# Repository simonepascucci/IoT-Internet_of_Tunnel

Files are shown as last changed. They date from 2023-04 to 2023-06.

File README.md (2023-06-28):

# IOT: Internet Of Tunnel

## People

| **Name and Surname** | **LinkedIn** | **GitHub** |
| :---: | :---: | :---: |
|  `Simone Pascucci` | name (https://www.linkedin.com/in/simone-pascucci-17751126b/) | name (https://github.com/simonepascucci) |
|  `Gavriel di Nepi` |  name (https://it.linkedin.com/in/gavriel-di-nepi-544a971b1)  | name (https://github.com/gaggo00) |
| `Davide Avesani` | name (https://www.linkedin.com/in/davide-avesani-394835223/)  | name (https://github.com/aveklan) |

## Brief description

Internet Of Tunnel project is a Monitoring and Control System solution designed to monitor and manage the air quality and lighting conditions inside a car tunnel.  
With this project, we aim to improve the air quality and light levels inside car galleries, in order to improve safety and health for tunnel users, both pedestrians and vehicles, while prioritizing energy efficiency.  
As part of our objectives, we are committed to reducing the overall system energy consumption, thereby promoting sustainability and minimizing environmental impact.

## First Delivery

### Documents

- [Concept](/docs/first_delivery/Concept.md)

- [Design](/docs/first_delivery/Design.md)

- [Evaluation](/docs/first_delivery/Evaluation.md)

### Video

- [Project Presentation](https://www.youtube.com/watch?v=qPwCQMbU30s)

## Second Delivery

- [2nd delivery](/docs/second_delivery/2nd%20delivery.md)
- [Concept](/docs/second_delivery/Concept.md)
- [Design](/docs/second_delivery/Design.md)
- [Evaluation](/docs/second_delivery/Evaluation.md)

## Third Delivery

- [Concept](/docs/third_delivery/Concept.md)
- [Design](/docs/third_delivery/Design.md)
- [Evaluation](/docs/third_delivery/Evaluation.md)

### Blog Post

- [Blog Post](https://www.hackster.io/internet-of-tunnel-sapienza-project-2023/iot-internet-of-tunnel-d4070c)

### Video

- [Video Presentation](https://youtu.be/nOzBFuhrOmo)
- [Video Demonstration](https://youtu.be/TSAeotWgk8Y)
  
### Presentation

- [Project Presentation](https://www.canva.com/design/DAFnCxpepLs/c_lBvF6-MGUBneV12p3HoQ/edit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)

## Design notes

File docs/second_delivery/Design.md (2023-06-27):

# Design

This file is an updated version of [this file](/docs/second_delivery/Design.md)

The proper functioning of the system depends on several complex technical aspects to be considered. In this section, we would like to address these issues in a real case scenario, describing the solutions and adaptations made to create the prototype.

## Technical aspects

The first step before starting the development and deployment of the system is a deep analysis of the specific characteristic of the tunnel and the regulations to be complied with.  
Considering that our project aims to automatically monitor and maintain the air quality and lighting conditions prioritizing energy efficiency, the main factors to be considered are:

1. It is essential to have a regulamentation that defines the rules to be respected, to properly design the system for the specific needing. The air quality system must be based on a list of air pollutants to be monitored and their respective threshold values. Also, the minimum level of light to be guaranteed inside the tunnel must be clearly defined.  
    To make consistent assumptions for the development of this project we referred to the current Ambient Air Quality and Clean Air for Europe Standards of 2008.  
    It exposes a list of a set of air elements harmful to humans, accompanied by their respective threshold levels and permissible maximum exposure durations.  
    The following list illustrates the components on the list generated by motor vehicles:
   | Pollutant | Formula | Maximum concentration | Maximum exposition time |
   | :----------------- | :-----: | --------------------: | ----------------------- |
   | carbon dioxide | CO2 | 1800 mg/m3 | 8 hour |
   | carbon monoxide | CO | 1000 mg/m3 | 15 minutes |
   | Nitrogen dioxide | NO2 | 200 mg/m3 | 1 hour |
   | Sulphur dioxide | SO2 | 350 mg/m3 | 1 hour |
   | Particulate matter | PM10 | 50 mg/m3 | 24 hour |

2. Once the regulamentation is clarified, it is necessary to understand the characteristics of the specific tunnel in terms of dimensions, expected traffic, type of users, normal light conditions etc.  
   This characteristic facilitates the comprehension of actuator specifications, determining the required quantity and strategic placements for optimal positioning.  
   Considering the environmental conditions is also crucial to enable connectivity of the monitoring system to the internet.

## Adapting the Prototype

We tried to design a prototype that reflects in a reasonable way a real case scenario, by making feasible estimations and assumptions in relation to the equipment at our disposal.
The dimensions of the cardboard used to simulate the tunnel are 50cm x 40cm x 80cm, resulting in a total air volume of 0.18m³.

### Sensors

**Air quality**  
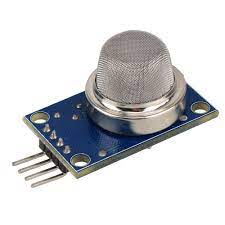
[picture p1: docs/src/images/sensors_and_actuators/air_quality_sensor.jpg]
  
The air quality sensor used is MQ-135 GAS SENSOR, suitable for detecting CO and CO2.  
This sensor vary the value of the R0 resistance depending on the concentrations of the various gases.  
The standard sensitivity characteristics of the MQ-135 sensor to different gases are illustrated below:
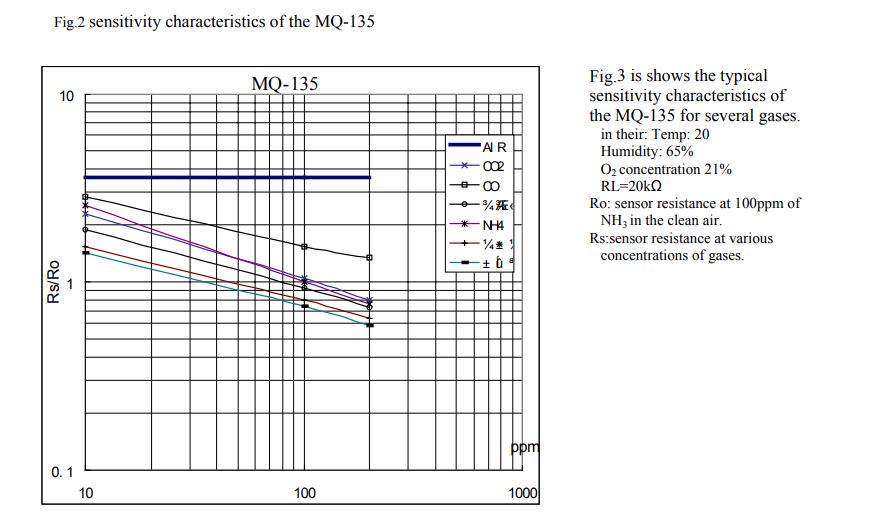
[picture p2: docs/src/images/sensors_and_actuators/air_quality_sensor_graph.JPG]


**Light**  
The light sensor used is BH1750FVI, a digital Ambient Light Sensor IC for I2C bus interface.

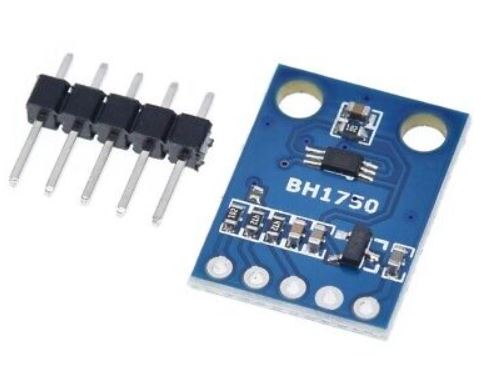
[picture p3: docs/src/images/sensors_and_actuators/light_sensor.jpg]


### Actuators

**Fan**  
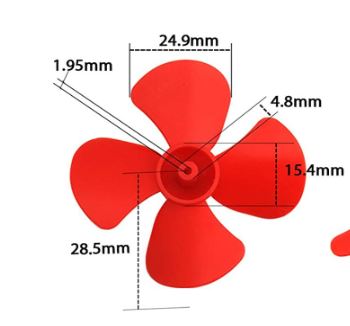
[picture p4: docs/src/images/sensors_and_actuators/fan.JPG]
  
We employed a simplistic method to estimate the fan airflow, considering that in the simulation scenario, this calculation serves as a rough approximation for guidance purposes, without requiring excessive complexity.  
The fan speed is controlled through PWM modulation, using three different speed settings.  
The formula results in:

**Airflow = fan · area · fan_speed · efficiency_factor**
| Data | value | units of measure |
| :--- | :-----: | --- |
| fan_max_speed | 44 | m/s |
| fan_mid_speed | 30 | m/s |
| fan_low_speed | 15 | m/s |
| effinciency_factor | 0.3|

| Airflow max speed | Airflow mid speed | Airflow low speed |
| :--- | :---: | --- |
| 0.033 m³/s | 0.023 m³/s | 0.011 m³/s |

With an energy consumprion of
| Airflow max speed | Airflow mid speed | Airflow low speed |
| :--- | :---: | --- |
| 100 mA | 90mA | 80mA |

Based on this estimation, we can determine the time it takes for a fan to circulate an air volume equivalent to that of the cardboard:

| Fan max speed | Fan mid speed | Fan low speed |
| :--- | :---: | --- |
| 6s | 8s | 17s |

**Light**

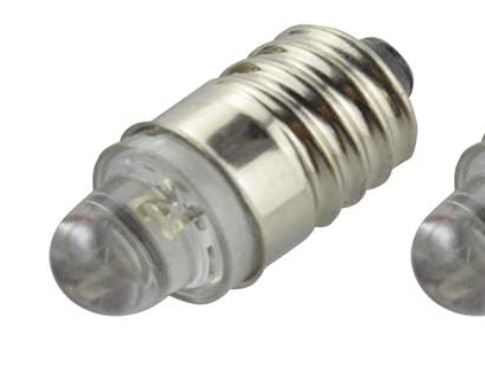
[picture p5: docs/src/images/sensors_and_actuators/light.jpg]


By positioning the light source on top of the cardboard, it generates a cone of light on the bottom with a radius of 15cm. Consequently, we opted to utilize six light bulbs to adequately illuminate the entire length of the cardboard. During measurements taken at the centre of the cone, the recorded light intensity reached approximately 1600 units.

## Managing the components

Based on the European standard mentioned earlier, the gases considered harmful to human health require a minimum exposure time of 15 minutes to pose a risk.  
We define 4 threshold of gas concentration as follows:

- **No risk treshold**: the gas concentrations are below the potentially harmful values for humans. Fan sistem is switched off.
- **Min risk treshold**: the gas concentrations are slightly above the potentially harmful values for humans. Fan sistem is switched on at 1/3 of maximum speed.
- **Mid risk treshold**: the gas concentrations are moderately above the potentially harmful values for humans. Fan sistem is switched on at 2/3 of maximum speed.
- **High risk treshold**: the gas concentrations are moderately above the potentially harmful values for humans. Fan sistem is switched on at maximum speed.

Under the condition of no risk treshold, it is reasonable to assume that monitoring air quality every 10 minutes provides a timely response from the air conditioning system.  
In the other conditions the graph below describes the different sampling period values.

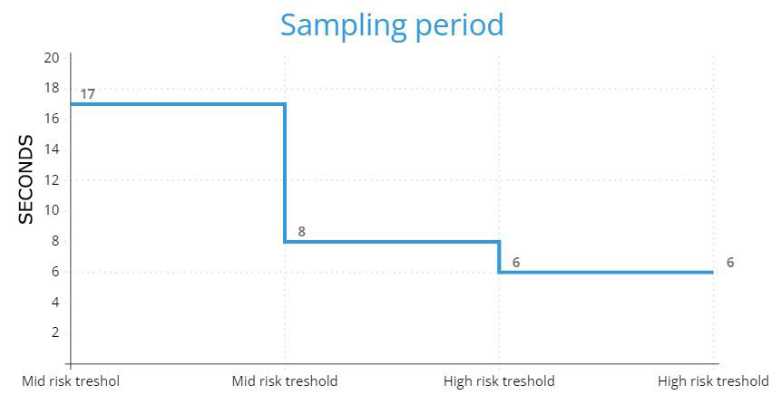
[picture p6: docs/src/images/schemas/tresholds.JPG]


The sampling period is based on the time needs for a fan to move a total volume of air equal to the volume of air of the tunnel.

## Circuit Diagrams

We utilized two separate breadboards, one for the lightning system and one for the other components as one power supply was not generating enough current.  
Additionally, it can be noticed that the DC motors are connected to a transistor rather than directly to the ESP32 PWM pin. This arrangement was necessary because the board alone can not generate enough current to power both motors. Using the transistor, the motors are supplied by the breadboard power supply, while the ESP32 exclusively controls their speed via PWM.

### Sensors & Air Conditioning System Diagram

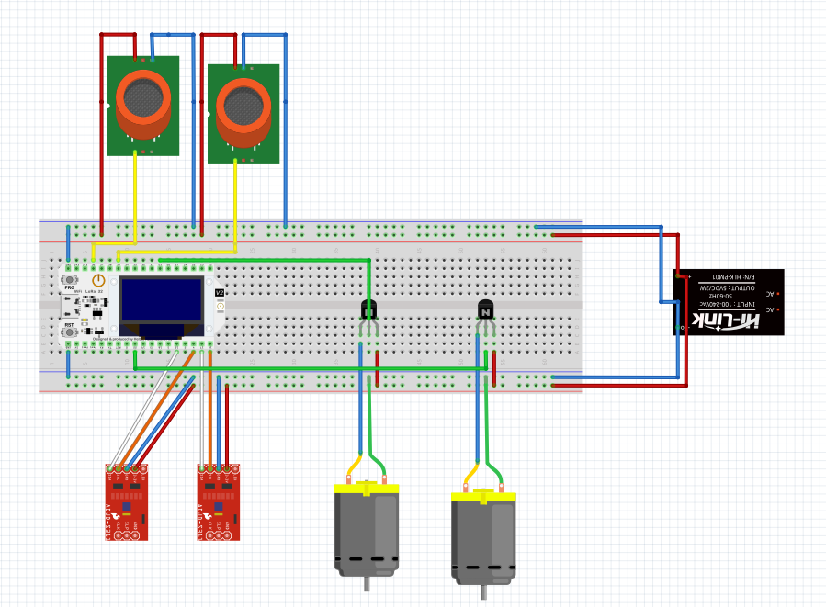
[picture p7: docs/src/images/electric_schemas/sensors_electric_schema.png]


### Lightning System Diagram

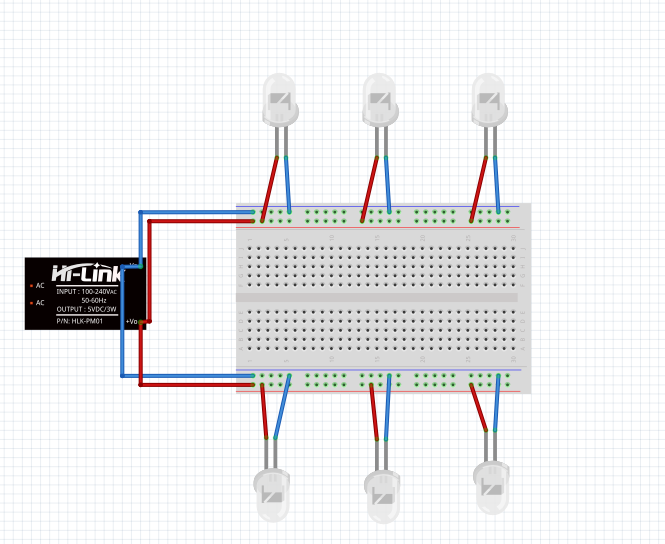
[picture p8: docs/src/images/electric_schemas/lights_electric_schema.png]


## Network architecture

The network architecture diagram and a brief description are as follows:

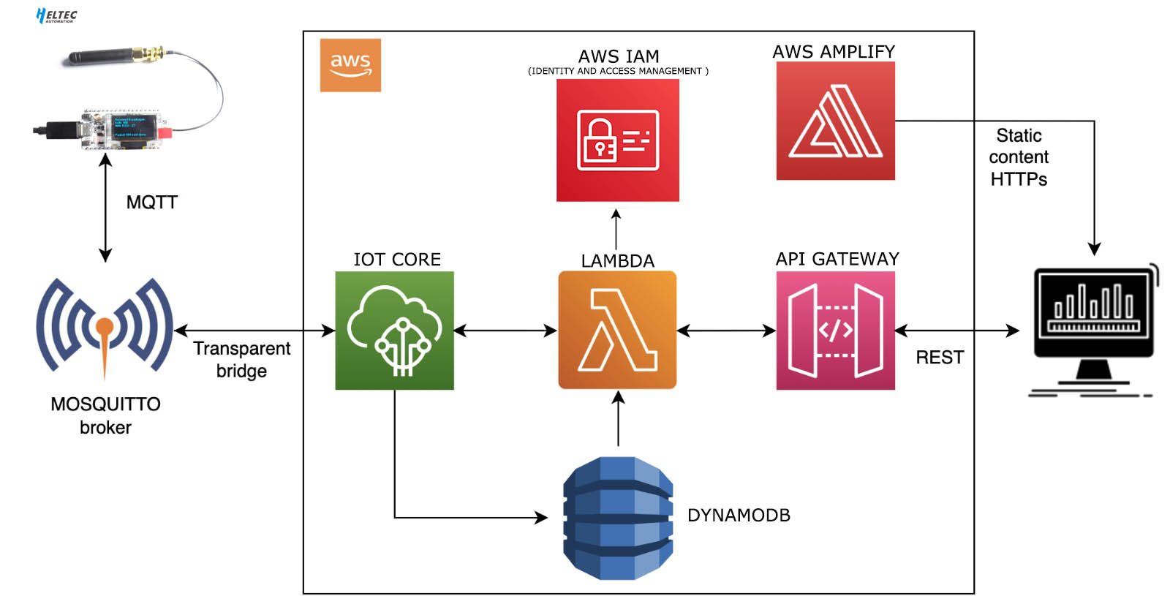
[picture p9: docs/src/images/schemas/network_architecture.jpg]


Step 1:  
ESP32 board sends data to Mosquitto MQTT broker, using the MQTT protocol. The connection is established over WiFi IPV4, with both devices connected to the same network.

Step 2:  
The broker communicates with AWS IoT Core through a Python bridge always trough the MQTT protocol. The MQTT broker and bridge utilize the same topic (tunnel), while the bridge publishes the data to AWS IoT Core on the DATA topic.

Step 3:  
Data is received on AWS IoT Core, designed as if it is an ESP32 board. This element allows to define rules to determine what actions to perform with the received data. In this way, all the data received on that specific topic is inserted into a table in DynamoDB.

Step 4:  
By utilizing a Lambda function (AWS Python function), data is retrieved from the DynamoDB. The authorization to access the database is managed by AWS IAM. The API Gateway enables the creation of a RESTful GET API connected to the Lambda function from the previous step, providing an endpoint that can be called from the web app.  
Amplify is the AWS hosting service used for deployment.

Below is a sample figure of the web app.

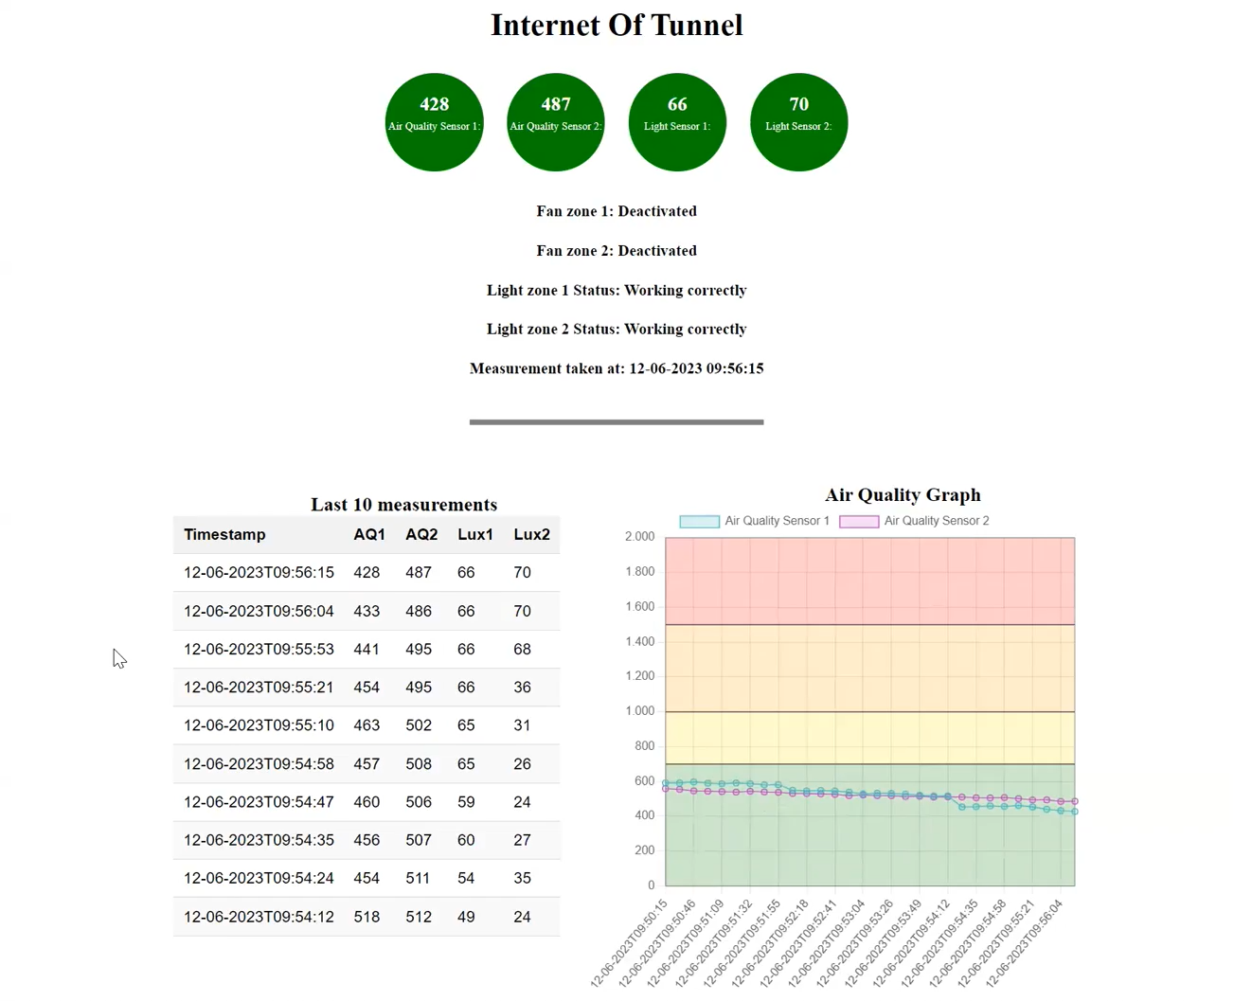
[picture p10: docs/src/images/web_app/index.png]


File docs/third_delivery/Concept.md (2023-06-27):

# Concept

This file is an updated version of [this file](/docs/second_delivery/Concept.md)

## Brief Description

Our project aims to employ a network of sensors and actuators to automate the management and monitoring of air quality and lighting conditions inside car galleries. We aim to offer a remote tool that enables remote monitoring providing a convenient means for continuous surveillance.  
The goal of this section is to provide users with a comprehensive overview of the smart tunnel, describing the system usage from their point of view.

## Tunnel operator point of view

### Deployment

To work properly, a set of sensors and actuators needs to be deployed inside the tunnel. To enable monitoring and management, it is essential that these units establish a direct connection to the board.  
The following schema provides a high level overview on how the components must be connected together.

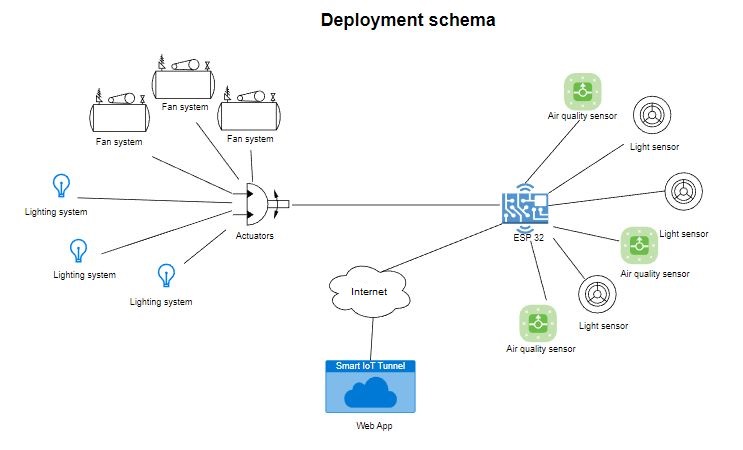
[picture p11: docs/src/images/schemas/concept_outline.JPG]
Project architecture outline


The following image shows a schematic representation of a tunnel, illustrating the positioning of sensors and actuators in a real use case.

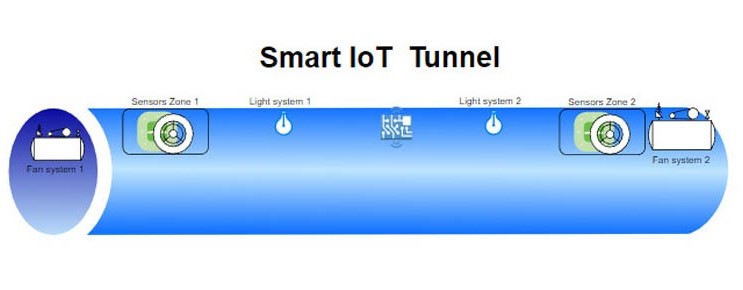
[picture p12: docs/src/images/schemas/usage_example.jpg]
Usage example


### Usage

To use the system, an operator simply needs to install the IoT sensors and actuators in the car gallery and connect them to the system's hub. Once the sensors are connected, they will begin collecting data on the air quality and lighting levels in the gallery.  
Based on the data collected, the system will automatically manage the air conditioning system to maintain optimal conditions inside the gallery. Moreover, it will be capable of promptly detect anomalies in the lightening apparatus and quickly inform the technicians.  
In addition, the data collected by the sensors will be tracked and transmitted to a remote server, where the operator will be able to access for remote monitoring.

## Tunnel user point of view

The entire system should operate seamlessly and without any noticeable impact on the regular users of the tunnels, including cars, motorcycles, and pedestrians. Transparency is key, ensuring that the system functions discreetly without causing disruption or inconvenience to those utilizing the tunnels.  
The normal users should only benefit of a more controlled and clean air.

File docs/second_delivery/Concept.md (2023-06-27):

# Concept

This file is an updated version of [this file](/docs/first_delivery/Concept.md)

## Brief Description

Our project aims to employ a network of sensors and actuators to automate and optimize the management and monitoring of air quality and lighting conditions inside car galleries. We aim to offer a remote tool that enables real-time monitoring and usage, providing a convenient means for continuous surveillance and utilization.  
The goal of this delivery is to provide readers with a comprehensive overview of the smart tunnel, detailing how the system works and illustrating technical data and assumptions.

## Tunnel operator point of view

### Deployment

To work properly, a set of sensors and actuators needs to be deployed inside the tunnel. To enable monitoring and management, it is essential that these units establish a direct connection to the board.  
The following schema provides a high level overview on how the components must be connected together.

Project architecture outline

The following image shows a schematic representation of a tunnel, illustrating the positioning of sensors and actuators in a prototype.

Usage example

### Monitoring and usage

The operators in charge of monitoring and utilization of the smart tunnel system will have access to a web app from which they will be able to check the current state of the tunnel. They will be able to monitor the data collected by the sensors, and to perform specific measurements on demand. This means that the operator is able change the measurement frequency rate and timing.  
This system also allows the operator to remotely control the actuators.  
The regulamentation for defining the designated individual in charge to perform these actions will follow the rules of the specific tunnel ordinance.

## Tunnel user point of view

The entire system should operate seamlessly and without any noticeable impact on the regular users of the tunnels, including cars, motorcycles, and pedestrians. Transparency is key, ensuring that the system functions discreetly without causing disruption or inconvenience to those utilizing the tunnels.  
The normal users should only benefit of a more controlled and clean air.

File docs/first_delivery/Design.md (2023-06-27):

# Design

## High level architecture

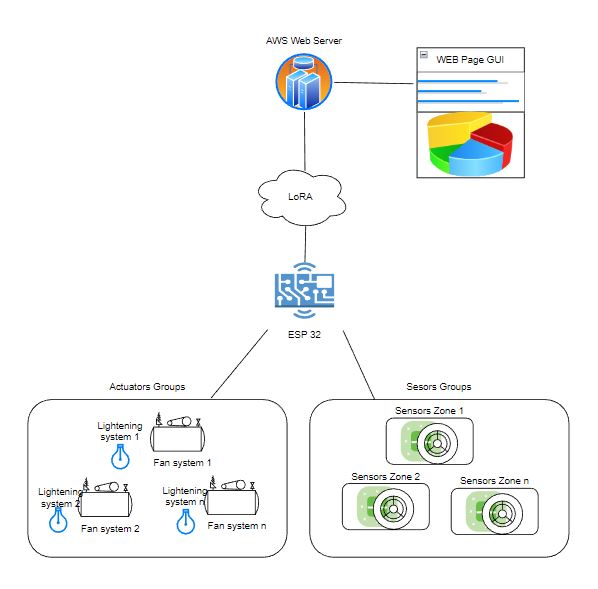
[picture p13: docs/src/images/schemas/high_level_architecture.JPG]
High Level Srchitecture
  
As shown in the picture, a set of sensors and actuators, grouped together in small clusters, are connected with an ESP32 controller.  
Based on the data received from the sensors, the controller manages the actuators by managing the speed/intensity and the switch-on state.  
The collected data will then be sent via the LoRa network to a remote AWS web server, where it will be stored for future analysis.

## Components

### Sensors

- Light sensor  
   Photoresistor  
   The light sensor is used to detect the level of light inside the gallery.  
   This sensor will be disposed in various strategic locations inside the gallery, in order to evaluate in which areas the lights have to be activated.

- Air quality sensor  
   Air quality sensor  
   The air quality sensor is used to detect the gas products generated by the combustion process in vehicle engines.  
   Also this sensor will be disposed in various strategic locations inside the gallery, in order to evaluate in which areas the fan system have to be activated.

### Actuators

- Fan system  
  A tunnel ventilation system is designed to perform the following functions:

  - Under normal operating conditions, dilute the gaseous products generated by the combustion process in vehicle engines and reduce the concentration of particulate matter.
  - In the event of an accident, extract and move, in a controlled manner, the smoke generated by fire events and clouds generated by gaseous phase releases of toxic and harmful substances and from liquid-phase spills of flammable substances.

  The ventilation consists in a set of electric motor actuators managed by the ESP32 controller connected to a fan to generate airflow.

- Lighting system  
  A lighting system is designed to perform the following functions:

  - Under normal operating conditions, lighten the tunnel to allow the normal movement of cars and pedestrians in safety.
  - In the event of an accident, activate the emergency lights to warn users and help them follow safety guidelines to stay safe inside the facility.

  The lightening consists in a set of actuator switches used to activate or deactivate the gallery lightening system and the traffic lights.

## Network

As mentioned at the beginning of this file, the data received by the sensors needs to be sent to a remote AWS web server.  
The connection between the ESP32 board and the IoT network works via the LoRa network to transmit the collected data, ensuring low power consumption.  
The ESP board will be placed in a position within the tunnel with LoRa network coverage.

## Web server

The web server is responsible of storing and managing the gathered information.  
It will be hosted on AWS and will provide a GUI to visualize and use the collected data.

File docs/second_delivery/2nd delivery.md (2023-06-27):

# 2nd delivery

## Comment received

The first observation we received was regarding the lack of data and numerical evidence to substantiate and validate our thesis.  
Consequently, our main objective for the second delivery is to conduct in-depth research and collect accurate data from both the real world scenarios and the simulation environment.  
The other observation we received was the lack of information regarding the technical aspects of implementing the network infrastructure. We therefore focused on the development and understanding of how to implement the network.  
A final minor observation involved the option of operating our system using an external power source, specifically a battery, in emergency situations. However, upon careful consideration, we have chosen not to implement this solution since on practical scenarios, it would be unrealistic to power all the actuators uniquely through a battery pack.

## Changes made

We adopted a new approach to tackle the problem, which influenced the design of the solution. Our new approach involves referring to a comprehensive set of guidelines and regulations from regulatory bodies that provide all the necessary data. By adhering to these regulations, we have structured our work to ensure compliance with the required standards.  
This approach did not change the overall architecture much but helped us to define how and when the system mst react in specific situations.  
Compared to the first delivery, we also redesigned the network infrastructure, avoiding the use of the LoRa network and adopting the use of MQTT.  
We finally decided to focus only on monitoring and managing the lighting conditions and air quality, by also promptly inform the operators in case of an emergency.

## Future improvements

The main functionality we intend to introduce with the third delivery is the inclusion of external data on hour-by-hour traffic forecasts. Our goal is to include this information in the algorithm that decides the sampling period, to optimise the overall performance of the system.
The web application is also still under development and has not yet been finalised. This application should comprehend an interface including graphical tools to help tunnel operators monitor the measured data.

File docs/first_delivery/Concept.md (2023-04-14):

# Concept

## Brief Description

Our project is designed to automatically manage and monitor the air quality and lighting conditions in a car gallery.  
To use the system, an operator simply needs to install the IoT sensors in the car gallery and connect them to the system's hub.  
Once the sensors are connected, they will begin collecting data on the air quality and lighting levels in the gallery.  
Based on the data collected, the system will automatically activate the lights and fans to maintain optimal conditions inside the gallery.  
In addition, the data collected by the sensors will be tracked and transmitted to a remote server, where they will be available for  
use in generating analyses and statistical data.

## Project Architecture

### Concept outline

Project architecture outline

### Usage example

Usage example

## Impact

Improving the overall air quality and light conditions inside the gallery, this project aims to reach two main goals:

- Reducing the overall number of car accidents inside the tunnel.
- Facilitate the use of the tunnel by pedestrians, where applicable.

These objectives are designed to be met in both normal and congested traffic situations.
In addition, the system is designed to use the various components only when necessary, allowing efficient use of energy.

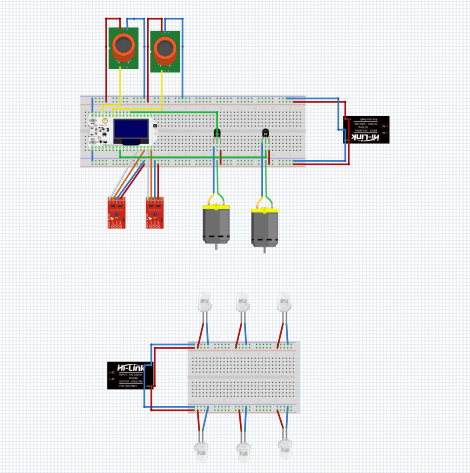
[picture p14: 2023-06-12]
docs/src/images/electric_schemas/sensors_and_lights_electric_schema.png

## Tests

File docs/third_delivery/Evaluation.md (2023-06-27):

# Evaluation

This file is an updated version of [this file](/docs/second_delivery/Evaluation.md)

## What needs to be evaluated

As discussed in detail in the Concept file, the aim of the project is to monitor air quality and lighting conditions inside car tunnels, with a focus on energy consumption.  
What needs to be evaluated is therefore the ability of the system to keep lighting and air quality conditions under control, as well as the overall energy utilization.  
Below is a brief explanation of the details of how these factors can be evaluated.

## Air quality

The project's objective related to air quality is to ensure that it remains below the threshold specified in the Design file, thereby maintaining a satisfactory level of air quality.  
In order for the system to be deemed effective, it is crucial that the levels of air quality pollutants do not exceed specified values for a duration that is considered harmful to human health. The specified time limit can be found in the Design file's table.  
After the initial version of the system is fully developed and deployed, it might be necessary to employ external sensors for monitoring purposes. These sensors would verify whether the values reported by the system align with the measurements obtained independently.

Finally, in order to analyze changes in air quality, we collected external data on traffic patterns from a website that provides a complete chronology of road travel times in recent years.  
We subsequently used this data to create a graph that illustrates the trend, as shown below.
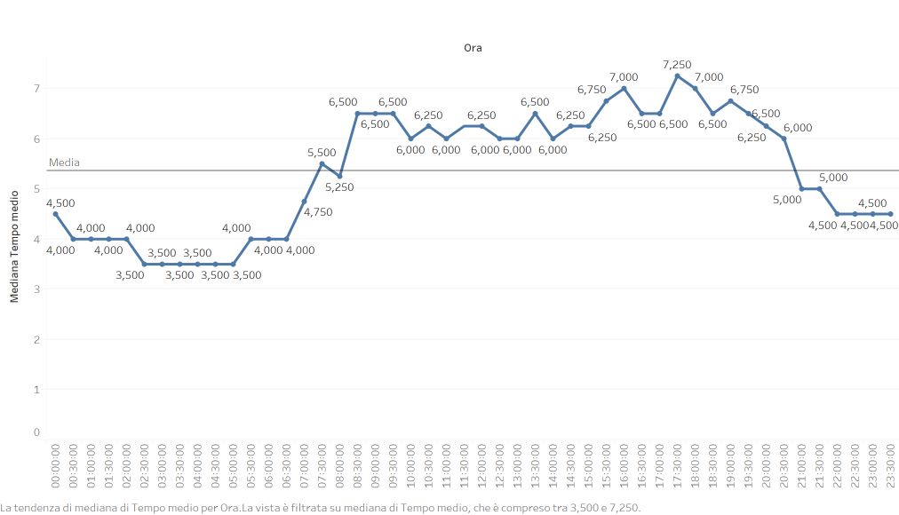
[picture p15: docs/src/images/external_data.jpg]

This enabled us to compare sensor readings with predicted air quality changes based on the traffic data.  
Similar trends indicate proper operation.
We tought to integrate this data through the APIs provided by the precedently mentioned website called OutScraper and accessible [at this link](https://outscraper.com).   
Unfortunately the service is not free so we weren't able to use the APIs in our prototype.

## Light conditions

In the context of ensuring an effective system, similar to air quality, it is crucial to guarantee minimum light values throughout the entire tunnel. Additionally, just like with the previous case, it may be necessary to incorporate external sensors for monitoring purposes after its full development and deployment.  
Finally, for the system to be considered effective, any error or failure in the lighting system must be promptly detected and notified to the operator.

## Overall energy usage

TThe energy consumption of the proposed system mostly depends on the actual energy requirements of the air conditioning system. This enables the system to intelligently activate or deactivate the actuators and adjust their intensity as needed, resulting in optimized energy usage. As a result, when traffic is low, our system consumes significantly less energy compared to a system that does not calibrate the usage of actuators and operates at maximum speed continuously.  
We performed some experiments with our prototype to better explain this concept trough an example.  
The following graph compares the power consumption of our system with an identical system in the same condition in which the fan system is always at maximum speed.  
Depending on the fan speed, our ventilation system is able to save up to 20% energy when activated at minimum speed.

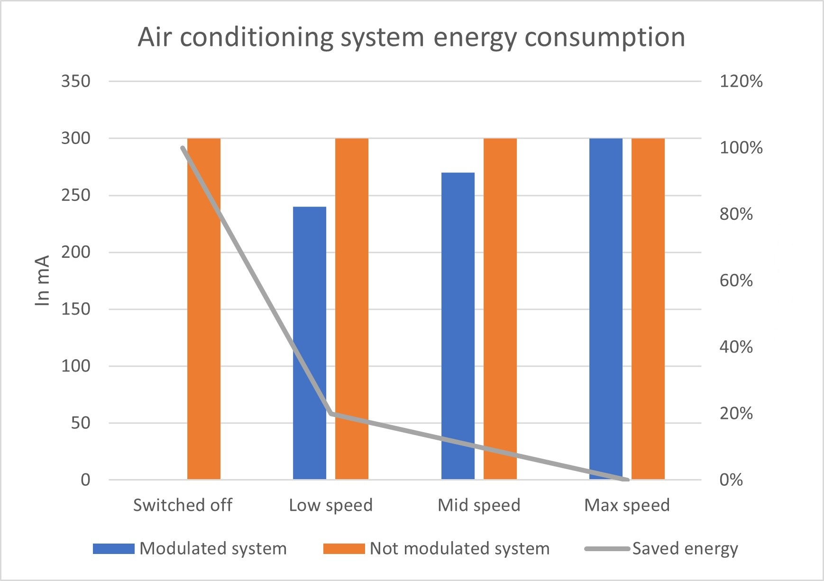
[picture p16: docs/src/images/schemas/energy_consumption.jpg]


The data on the power consumption used for creating this graph are the one reported in the Design file.  
Notice that this is an example performed on our prototype but that can also be extended in a real case scenario with the right adjustments.

## Network

Our network architecture has been designed in a way that doesn't raise any specific criticisms. However, it is important to ensure that the board can establish a connection with the MQTT bridge, and from there, maintain a stable internet connection.

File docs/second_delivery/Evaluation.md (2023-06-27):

# Evaluation

This file is an updated version of [this file](/docs/first_delivery/Evaluation.md)

## What needs to be evaluated

As discussed in detail in the Concept file, the aim of the project is to monitor air quality and lighting conditions inside car tunnels, with a focus on energy consumption.  
What needs to be evaluated is therefore the ability of the system to keep lighting and air quality conditions under control, as well as the overall energy utilization.  
Below is a brief explanation of the details of how these factors can be evaluated.

## Air quality

The project's objective related to air quality is to ensure that it remains below the threshold specified in the Design file, thereby maintaining a satisfactory level of air quality.  
In order for the system to be deemed effective, it is crucial that the levels of air quality pollutants do not exceed specified values for a duration that is considered harmful to human health. The specified time limit can be found in the Design file's table.  
After the initial version of the system is fully developed and deployed, it might be necessary to employ external sensors for monitoring purposes. These sensors would verify whether the values reported by the system align with the measurements obtained independently.  
As a future improvement, we would like to make use external data predictions on traffic conditions on which we will base our evaluation.

## Light conditions

In the context of ensuring an effective system, similar to air quality, it is crucial to guarantee minimum light values throughout the entire tunnel. Additionally, just like with the previous case, it may be necessary to incorporate external sensors for monitoring purposes after its full development and deployment.

## Overall energy usage

The energy consumption of the proposed system mostly depends on the actual energy requirements of the actuators, especially of the air conditioning system. This enables the system to intelligently activate or deactivate the actuators and adjust their intensity as needed, resulting in optimized energy usage. As a result, when traffic is low or there is enough natural light coming from the outside, our system can consume significantly less energy compared to a system that does not calibrate the usage of actuators and operates at maximum speed continuously.  
We performed some experiments with our prototype to better explain this concept trough an example.  
The following graph compares the power consumption of our system with an identical system in the same condition in which the fan system is always at maximum speed.  
Depending on the fan speed, our ventilation system is able to save up to 20% energy when activated at minimum speed.



The data on the power consumption used for creating this graph are the one reported in the Design file.  
Notice that this is an example performed on our prototype but that can also be extended in a real case scenario with the right adjustments.

## Network

Our network architecture has been designed in a way that doesn't raise any specific criticisms. However, it is important to ensure that the board can establish a connection with the MQTT bridge, and from there, maintain a stable internet connection.

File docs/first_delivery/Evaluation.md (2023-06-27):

# Evaluation

## Overview

The IoT project is designed to monitor air quality and light levels inside a tunnel. Some air quality sensors and some photoresistor are used to collect data in real-time. The system is connected to some actuators that activates the fan system when the air quality decreases below a certain threshold, and the lighting system that turn on independently when the light levels fall below a certain value.

## Performance evaluation metrics

### Accuracy

The accuracy of the system is a key performance metric. The solution in question, must accurately measure and detect changes in air quality and light levels.
The overall values detected must remain inside a defined range to consider the solution effective.

### Responsiveness

The responsiveness of the system is also important. The system should respond to changes in air quality and light levels, to ensure the correct functioning, also in case of emergency situations.
One way to evaluate this parameter would be to expose it to specific changes in air quality and light levels and measure the time it takes to reach the predefined range after these changes.

## Expected results

As mentioned before, to consider the system effective, the overall values detected must remain below a defined treshold. We therefore expect that our system is capable of managing different traffic situations and lightning conditions by keeping the values in question inside the correct ranges.  
As a prerequisite for achieving this behaviour, we expect the accuracy of the system to be good enough to allow the system to detect and react to specific situations and requirements in a reasonable amount of time.

As a consequence, we expect a decrease in the number of car accident inside the gallery and a more efficient power management.

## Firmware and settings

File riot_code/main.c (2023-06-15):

#include "stdio.h"
#include "stdlib.h"

#include "paho_mqtt.h"
#include "MQTTClient.h"

#include "xtimer.h"
#include "ztimer.h"

#include "time.h"
#include "thread.h"

#include "bh1750fvi.h"
#include "periph/pwm.h"
#include "periph/adc.h"
#include "periph/gpio.h"

//MQTT settings
#define BUF_SIZE 1024

#define MQTT_VERSION_v311               4       /* MQTT v3.1.1 version is 4 */
#define COMMAND_TIMEOUT_MS              4000

#define BROKER_ADDRESS "172.20.10.2"
#define DEFAULT_MQTT_PORT               1883
#define DEFAULT_KEEPALIVE_SEC           10
#define TOPIC "Tunnel"

#define IS_CLEAN_SESSION                1
#define IS_RETAINED_MSG                 0

#define  AQ_MINRISK  700
#define AQ_MIDRISK  1000
#define AQ_MAXRISK  1500

#define L_THRESHOLD 30

static MQTTClient client;
static Network network;
static unsigned char buf[BUF_SIZE];
static unsigned char readbuf[BUF_SIZE];

// Pin used to lights control
#define LIGHT_ZONE_0 GPIO21
#define LIGHT_ZONE_1 GPIO13

// Pin used for fan control
#define FAN_ZONE_0 PWM_DEV(0)
#define FAN_ZONE_1 PWM_DEV(1)

// Define PWM parameters
pwm_t fan0 = FAN_ZONE_0;
pwm_t fan1 = FAN_ZONE_1;
uint32_t freq = 1000;
uint16_t res = 1500;
uint16_t minSpeed = 500;
uint16_t midSpeed = 1000;
uint16_t maxSpeed = 1500;

bh1750fvi_t light_zone_0_sensor;
bh1750fvi_t light_zone_1_sensor;
bh1750fvi_params_t light_zone_0_params = {
    .i2c = I2C_DEV(0),
    .addr = BH1750FVI_DEFAULT_ADDR};
bh1750fvi_params_t light_zone_1_params = {
    .i2c = I2C_DEV(1),
    .addr = BH1750FVI_DEFAULT_ADDR};

uint16_t light_zone_0_value;
uint16_t light_zone_1_value;

// Define gas sensor paramiters
#define RL_VALUE 10.0
#define RO_CLEAN_AIR_FACTOR 3.6
#define ADC_RES ADC_RES_12BIT
#define ADC_MAX (1 << ADC_RES) - 1
#define R_LOAD 10.0

uint_fast8_t air_quality_zone_0_sensor = ADC_LINE(0); // Pin 36
uint_fast8_t air_quality_zone_1_sensor = ADC_LINE(1); // Pin 39
int32_t air_quality_zone_0_value;
int32_t air_quality_zone_1_value;

#define SAMPLING_PERIOD 7

void activateLightZone(gpio_t light_zone)
{
    gpio_set(light_zone);
    puts("attivo light zone");
}
void deactivateLightZone(gpio_t light_zone)
{
    gpio_clear(light_zone);
    puts("disattivo light zone");
}

void activateFanZone(pwm_t fan_zone, uint16_t res)
{
    pwm_set(fan_zone, 0, res);
    //pwm_poweron(fan_zone);
}

void deactivateFanZone(pwm_t fan_zone)
{
    pwm_poweroff(fan_zone);
}

uint16_t sampleLight(bh1750fvi_t *light_sensor)
{
    return bh1750fvi_sample(light_sensor);
}

int32_t sampleAir(uint_fast8_t air_quality_zone, uint16_t res)
{
    return adc_sample(air_quality_zone, ADC_RES);
}

int initialize_sensors_and_actuators(void){

    // Inizialize light actuators
    if(gpio_init(LIGHT_ZONE_0, GPIO_OUT) || gpio_init(LIGHT_ZONE_1, GPIO_OUT)){
        puts("Led initialization failed!");
    }
    activateLightZone(LIGHT_ZONE_0);
    activateLightZone(LIGHT_ZONE_1);

    //Initialize BH1750 light sensors
    bh1750fvi_init(&light_zone_0_sensor, &light_zone_0_params);
    bh1750fvi_init(&light_zone_1_sensor, &light_zone_1_params);

    //Initialize fan actuators
    if (!pwm_init(PWM_DEV(fan0), PWM_LEFT, freq, res) || !pwm_init(PWM_DEV(fan1), PWM_LEFT, freq, res))
        puts("PWM Initialization failed.\n");
    
    if (adc_init(air_quality_zone_0_sensor) ||
        adc_init(air_quality_zone_1_sensor))
        puts("Air quality sensor initialization failed\n");
    
    return 0;
}


int mqtt_init(void){

    xtimer_sleep(5);

    NetworkInit(&network);
    MQTTClientInit(&client, &network, COMMAND_TIMEOUT_MS, buf, BUF_SIZE, readbuf, BUF_SIZE);
    MQTTStartTask(&client);

    MQTTPacket_connectData data = MQTTPacket_connectData_initializer;
    data.MQTTVersion = MQTT_VERSION_v311;
    data.clientID.cstring = "";
    data.username.cstring = "";
    data.password.cstring = "";
    data.keepAliveInterval = 60;
    data.cleansession = 1;

    printf("MQTT: Connecting to MQTT Broker from %s %d\n",
            BROKER_ADDRESS, DEFAULT_MQTT_PORT);
    printf("MQTT: Trying to connect to %s, port: %d\n",
            BROKER_ADDRESS, DEFAULT_MQTT_PORT);
    
    int res = NetworkConnect(&network, BROKER_ADDRESS, DEFAULT_MQTT_PORT);

    if(res){
        printf("MQTT unable to connect: Error %d\n", res);
        return res;
    }
    res = MQTTConnect(&client, &data);

    if (res < 0) {
        printf("MQTT: Unable to connect client %d\n", res);
        int res = MQTTDisconnect(&client);
        if (res < 0) {
            printf("MQTT: Unable to disconnect\n");
        }
        else {
            printf("MQTT: Disconnect successful\n");
        }
        NetworkDisconnect(&network);
        return res;
    }
    else{
        printf("MQTT: Connection success!\n");
    }

    printf("MQTT client succesfully connected to the broker\n");
    return 0;
}

int main(void)
{   
    if (mqtt_init()){
        printf("MQTT initialization error...!\n");
    }else printf("MQTT initialization success\n");

    if(initialize_sensors_and_actuators())
        printf("Sensors and actuators initialization error!\n");
    else
        printf("Sensor and actuators initialization success!\n\n");

    int i = 0;

    int l1status, l2status;
    char* statusAQ1 = "";
    char* statusAQ2 = "";


    while (1){

    int t0 = sampleLight(&light_zone_0_sensor);
    if (t0 < 1000 && t0 > 0) light_zone_0_value = t0;
    printf("Light Zone 0 Value: %d\n", light_zone_0_value);

    xtimer_sleep(1);

    int t1 = sampleLight(&light_zone_1_sensor);
    if (t1 < 1000 && t1 > 0) light_zone_1_value = t1;
    else if (t1 < 150) light_zone_1_value = t1;
    printf("Light Zone 1 Value: %d\n", light_zone_1_value);

    xtimer_sleep(1);

    if (light_zone_0_value <= L_THRESHOLD)
        l1status = 0;
    else l1status = 1;

    if (light_zone_1_value <= L_THRESHOLD)
        l2status = 0;
    else l2status = 1;

    air_quality_zone_0_value = sampleAir(air_quality_zone_0_sensor, ADC_RES);
    printf("Air quality Zone 0 Value: %d\n", air_quality_zone_0_value);

    xtimer_sleep(1);

    air_quality_zone_1_value = sampleAir(air_quality_zone_1_sensor, ADC_RES);
    printf("Air quality Zone 1 Value: %d\n", air_quality_zone_1_value);

    xtimer_sleep(1);

    if (air_quality_zone_0_value < AQ_MINRISK) {
        statusAQ1 = "SAFE";
        activateFanZone(FAN_ZONE_0, 0);
        printf("Deactivating fan zone 0\n");
    }
    else if (air_quality_zone_0_value >= AQ_MINRISK && air_quality_zone_0_value < AQ_MIDRISK) {
        statusAQ1 = "MIN_RISK";
        activateFanZone(FAN_ZONE_0, minSpeed);
        printf("Fan zone 0 min speed\n");
    }
    else if (air_quality_zone_0_value >= AQ_MIDRISK && air_quality_zone_0_value < AQ_MAXRISK) {
        statusAQ1 = "MID_RISK";
        activateFanZone(FAN_ZONE_0, midSpeed);
        printf("Fan zone 0 mid speed\n");
    }
    else if (air_quality_zone_0_value >= AQ_MAXRISK) {
        statusAQ1 = "MAX_RISK";
        activateFanZone(FAN_ZONE_0, maxSpeed);
        printf("Fan zone 0 max speed\n");
    }


    if (air_quality_zone_1_value < AQ_MINRISK) {
        statusAQ2 = "SAFE";
        activateFanZone(FAN_ZONE_1, 0);
        printf("Deactivating fan zone 1\n");
    }
    else if (air_quality_zone_1_value >= AQ_MINRISK && air_quality_zone_1_value < AQ_MIDRISK) {
        statusAQ2 = "MIN_RISK";
        activateFanZone(FAN_ZONE_1, minSpeed);
        printf("Fan zone 1 min speed\n");
    }
    else if (air_quality_zone_1_value >= AQ_MIDRISK && air_quality_zone_1_value < AQ_MAXRISK) {
        statusAQ2 = "MID_RISK";
        activateFanZone(FAN_ZONE_1, midSpeed);
        printf("Fan zone 1 mid speed\n");
    }
    else if (air_quality_zone_1_value >= AQ_MAXRISK) {
        statusAQ2 = "MAX_RISK";
        activateFanZone(FAN_ZONE_1, maxSpeed);
        printf("Fan zone 1 max speed\n");
    }

    char json[256];

    sprintf(json, "{\"id\": \"%d\", \"AirQuality1\": \"%d\", \"AirQuality2\": \"%d\", \"LightLevel1\": \"%d\", \"LightLevel2\": \"%d\", \"StatusL1\": \"%d\", \"StatusL2\": \"%d\", \"StatusAQ1\": \"%s\", \"StatusAQ2\": \"%s\"}",
                        i, air_quality_zone_0_value, air_quality_zone_1_value, light_zone_0_value, light_zone_1_value, l1status, l2status, statusAQ1, statusAQ2);

    char* msg = json;

    //MQTT publish
    MQTTMessage message;
    message.qos = QOS1;
    message.retained = IS_RETAINED_MSG;
    message.payload = msg;
    message.payloadlen = strlen(message.payload);

    int rp = MQTTPublish(&client, TOPIC, &message);
    if (rp){
        printf("MQTT error %d: unable to publish!\n", rp);
    }else{
        printf("MQTT message published succesfully to topic %s\n", TOPIC);
    }

    i++;

    xtimer_sleep(SAMPLING_PERIOD);
    }

    return 0;
}

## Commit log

2023-06-12 Added circuit diagrams
2023-06-12 Added electric schemas
    [electric_schema.fzz]
